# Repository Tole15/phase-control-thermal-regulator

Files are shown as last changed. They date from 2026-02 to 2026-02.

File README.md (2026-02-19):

# ⚡ Phase-Synchronized Thermal Regulation System

## AC Phase-Control via Zero-Cross Detection & Discrete PI Control






---

## 📌 Overview

This project implements a **closed-loop thermal regulation system** using **phase-angle control** for AC resistive loads.  
TRIAC firing is synchronized with **mains zero-cross events**, while temperature is regulated using a **discrete-time PI controller**.

✔ Hardware validated at **127V / 60Hz**  
✔ Real-time zero-cross synchronization (120 Hz)  
✔ Deterministic discrete control loop (2 Hz)

---

## 🧠 System Architecture

### Control Strategy

- **Control Loop Frequency:** 2 Hz (Update every 0.5 s)
- **Zero-Cross Synchronization:** 120 Hz (Every half-cycle)
- **Sampling Time (Ts):** 0.5 s

The system measures temperature using an **LM35 sensor**, processes the signal through a discrete PI controller, and modulates AC power via TRIAC phase-angle control.

---

## 🔌 Hardware Architecture

### 🔹 Control & Synchronization

- **Microcontroller:** ATmega328P (Arduino platform)
- **Zero-Cross Detection:**
  - 2W10G Bridge Rectifier
  - PC817 Optocoupler
- **Interrupt:** INT0 (External interrupt)
- **Timer:** Timer1 (High-precision firing delay generation)

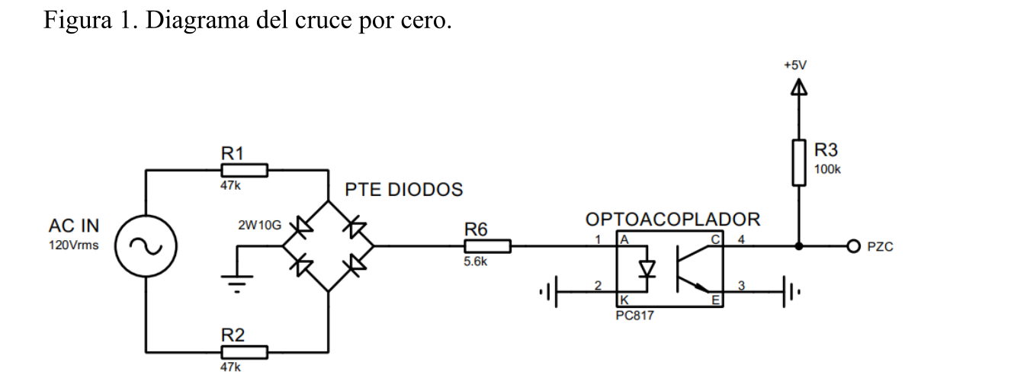
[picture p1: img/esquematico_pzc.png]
Zero Cross Circuit


---

### 🔹 Power Stage

- **Opto-Driver:** MOC3021
- **Power TRIAC:** BTA06-600BW
- **Load:** 75W AC Resistive (Heating element / Incandescent lamp)

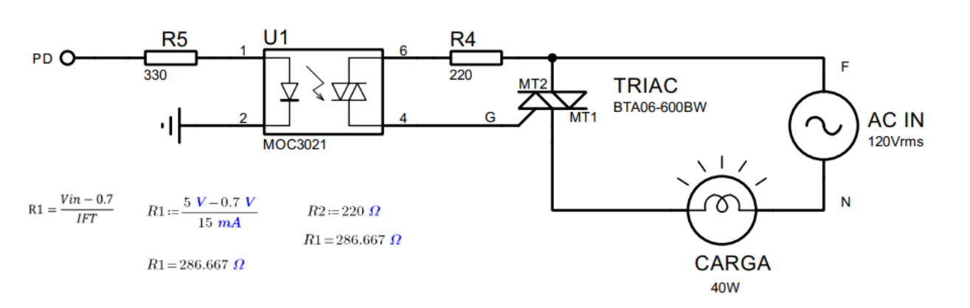
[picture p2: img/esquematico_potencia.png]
Power Stage


---

### 🔹 Sensor & Signal Conditioning

- **Sensor:** LM35 Linear Temperature Sensor
- **Signal Conditioning:**
  - Active filtering
  - Operational amplifier scaling
  - Full 0–5V ADC utilization (10-bit resolution)

---

## 📊 Signal Validation

Oscilloscope verification confirms correct synchronization between:

- 🔵 AC waveform
- 🟡 Zero-cross detection pulse

| Parameter | Measured Value |
|---|---|
| PZC Frequency | 120.0 Hz |
| Half-cycle Period | 8.33 ms |
| PZC Vpp | 3.00 V |

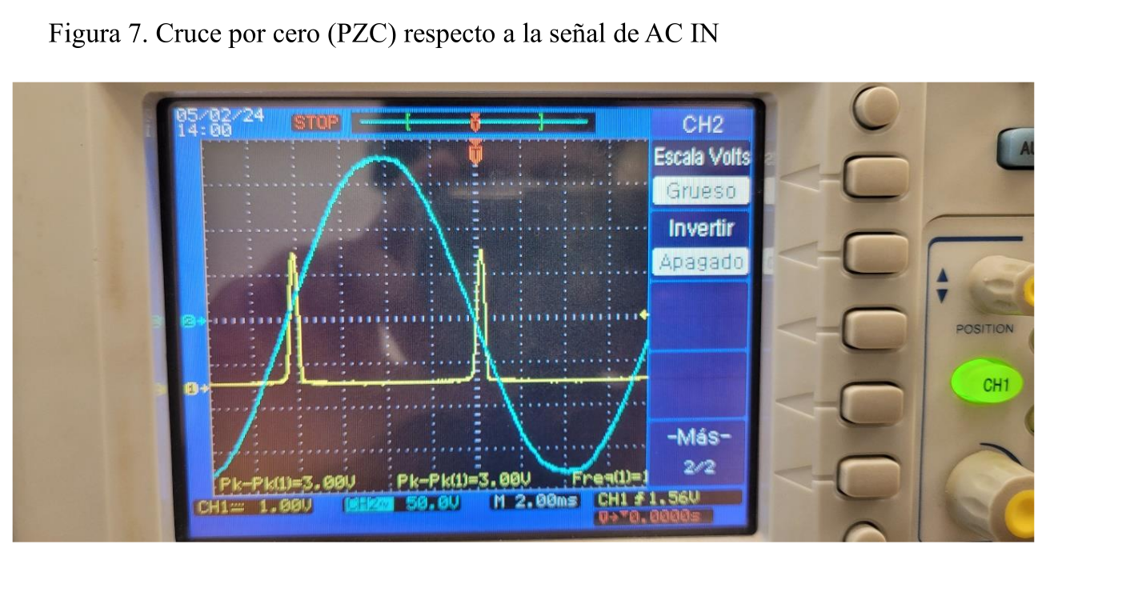
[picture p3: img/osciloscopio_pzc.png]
Oscilloscope Validation


---

## 🧮 Discrete PI Controller

Recursive implementation:

```
u(k) = u(k-1) + q0·e(k) + q1·e(k-1)
```

Using trapezoidal (Tustin) approximation:

```
q0 = Kp + (Ki·Ts)/2
q1 = (Ki·Ts)/2 - Kp
```

### Variables

- `e(k)` → Current error (Setpoint − Measured temperature)
- `u(k)` → Control effort (Mapped to conduction angle)

---

## 🔥 Power Modulation

The PI output is mapped to a Timer1 compare value.

TRIAC firing delay:

```
t_delay = t_half_cycle - t_conduction
```

Output saturation ensures safe operation:

```
0 ≤ CMP ≤ ICR1
```

---

## 🖥 PCB Design

The PCB integrates:

- Zero-cross detection stage
- Opto-isolated TRIAC driver
- Power switching stage

Design considerations:

- Track width for load current handling
- Isolation spacing for safety
- Noise-aware layout

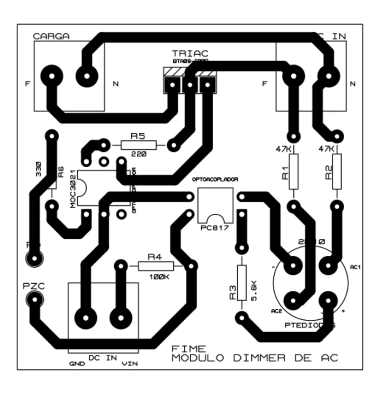
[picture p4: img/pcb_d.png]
PCB Layout


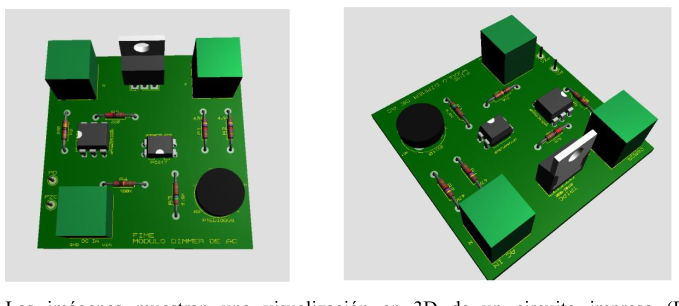
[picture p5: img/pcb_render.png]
PCB 3D Render


---

## 📊 Results / Experimental Response Plot

The closed-loop thermal response was experimentally validated under step reference conditions.

### 🔹 Step Response Test

- Initial Temperature: Ambient (~25°C)
- Setpoint: 28°C (Short-range validation test)
- Control Mode: Discrete PI (Ts = 0.5 s)
- Load: 75W resistive heater

Observed behavior:

- Smooth temperature rise
- No sustained oscillations
- Stable steady-state regulation
- Minimal steady-state error

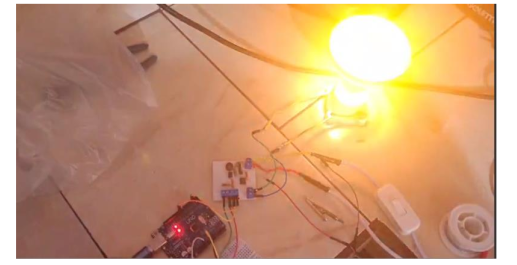
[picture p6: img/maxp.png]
Maximum Power Test


*Figure 1: System response under maximum conduction angle.*

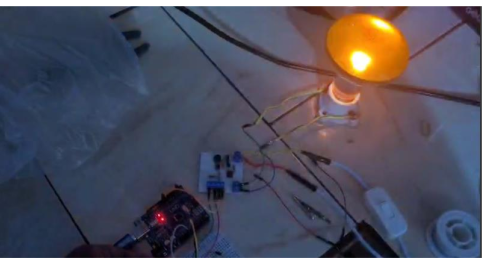
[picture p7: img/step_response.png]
Closed-Loop Step Response


*Figure 2: Experimental closed-loop temperature response near target setpoint.*

---

## 🧮 Mathematical Modeling

The thermal plant is approximated as a first-order system:

```
G(s) = K / (τs + 1)
```

Where:

- `K` → Thermal gain
- `τ` → Thermal time constant

Considering phase-angle modulation, the effective RMS power delivered to the load as a function of firing angle (α) is:

```
P(α) ≈ (Vm² / 2R) · (1/π) · (π - α + 0.5·sin(2α))
```

The discrete-time controller is derived using the Tustin transformation:

```
s ≈ (2/Ts) · (z - 1)/(z + 1)
```

Closed-loop transfer function (idealized continuous model):

```
T(s) = (Gc(s)G(s)) / (1 + Gc(s)G(s))
```

Where:

```
Gc(s) = Kp + Ki/s
```

---

## 📂 Repository Structure

```
├── firmware/
│   └── arduino/
│       └── main.ino        # PI Control + Zero-Cross ISR logic
├── docs/
│   ├── Practica7.pdf       # Experimental report
│   └── diagrama.pdf        # Block diagram
└── hardware/
    └── cadcam/             # Gerber files / PCB design
```

---

## 🚀 Key Features

- Deterministic phase-angle control
- Hardware-level synchronization
- Discrete PI digital implementation
- Interrupt-driven architecture
- Experimental hardware validation

---

## 📈 Applications

- Temperature regulation systems
- Industrial heating control
- AC power modulation
- Embedded control education
- Digital control system demonstrations

---

## 📜 License

This project is provided for academic and educational purposes.

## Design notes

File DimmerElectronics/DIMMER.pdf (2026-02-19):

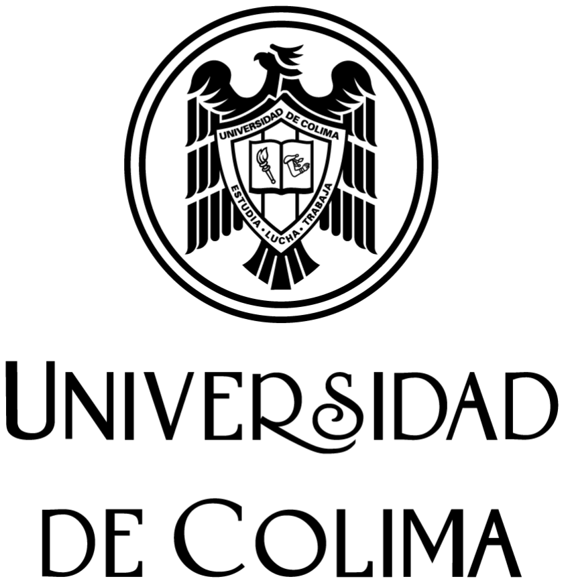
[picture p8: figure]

# Práctica 7: Módulo dimmer de AC

## César Alejandro Tolentino Mendoza Aitor Sebastián Larios Cuevas Gilberto Linares Jaime Arnoldo Valencia Gallardo Francisco Javier Carrillo Farías

## Laboratorio de Microelectrónica, 02 de mayo de 2024

### Profesora: Sonia Martínez Camarena Facultad de Ingeniería Mecánica y Eléctrica Universidad de Colima Ingeniería en Sistemas Electrónicos y de Telecomunicaciones, 4to C Circuitos de Corriente Alterna

# Índice

Introducción | 3
Detecció n de Cruce pór Ceró | 3
Cóntról de Á nguló de Disparó | 3
Objetivos | 4
Objetivó General | 4
Objetivós Especí ficós | 4
Desarrollo de la Práctica | 4
Detectór de cruce pór ceró: | 4
Simulació n de la sen al de salida del detectór de cruce pór ceró: | 6
Circuitó de cóntról de pótencia cón TRIÁC | 7
Funciónamientó del Circuitó | 8
Móduló dimmer ÁC | 9
Cónstrucció n del mó duló dimmer ÁC | 10
Resultados Obtenidos | 11
Cónstrucció n y pruebas del funciónamientó esperadó del Mó duló Dimmer ÁC | 11
Có digó de Árduinó para generar PWM cómó sen al de cóntról de la pótencia en la carga | 13
Explicació n de la Biblióteca PWMUNO | 13
Có digó para manejó de pótencia a trave s de un pótenció metró | 13
Pruebas de funciónamientó | 14
Conclusión | 15
Bibliografía | 15

# Introducción

Un dimmer es un dispositivo diseñado para ajustar la potencia entregada a una carga eléctrica, como una lámpara o un motor, mediante la modulación del voltaje que recibe. Esta capacidad de ajuste no solo permite controlar la intensidad de la luz o la velocidad de un motor, sino que también contribuye a la eficiencia energética y la extensión de la vida útil de los dispositivos eléctricos.

En aplicaciones modernas, especialmente en automatización del hogar y sistemas industriales, los dímmers pueden ser controlados digitalmente, ofreciendo mayor precisión y facilidad de integración con otros sistemas digitales. Un ejemplo prominente de este enfoque digital es el uso de un Arduino para controlar un dimir. Arduino puede enviar señales a un dimmer para ajustar el voltaje de salida basado en entradas programáticas o condiciones sensoriales.

El control preciso del dimmer se logra mediante dos técnicas principales: la detección de cruce por cero y el control de ángulo de disparo del TRIAC.

# Detección de Cruce por Cero

Para lograr un control efectivo y eficiente del dimmer, empleamos la técnica de detección de cruce por cero. Este método consiste en identificar el momento exacto en que la corriente alterna (CA) cambia de dirección, pasando por 0 Volts. Esta detección es crucial para sincronizar la activación del dimmer con la frecuencia de la red eléctrica.

# Control de Ángulo de Disparo

El control del dimmer se perfecciona mediante el control de ángulo de disparo. Esta técnica implica determinar el punto exacto del ciclo de CA en el que se permite que el TRIAC (componente clave en el control de potencia) conduzca corriente hacia la carga. Modificar el ángulo de disparo del TRIAC altera la cantidad de energía transmitida a la carga durante cada ciclo de CA, permitiendo un ajuste fino de la potencia suministrada. En la práctica, ajustamos este ángulo mediante programación en el Arduino para responder a las necesidades específicas del proyecto.

# Objetivos

# Objetivo General

Diseñar, simular y construir un módulo dimmer utilizando un TRIAC en sincronía con la corriente alterna (VCA), controlado por Arduino.

# Objetivos Específicos

- Simular el funcionamiento del módulo dimmer en software especializado.
- Construir el circuito en protoboard y realizar pruebas para validar el diseño.
- Diseñar y fabricar un PCB para el módulo dimmer.

# Desarrollo de la Práctica

La práctica se enfocó en el diseño, simulación y construcción de un módulo dimmer que utiliza un TRIAC para controlar la potencia en sincronía con la corriente alterna (VCA), todo ello gestionado mediante un Arduino. Los componentes seleccionados para este proyecto incluyeron resistencias de diversos valores (47k ohm, 220 ohm, 330 ohm, 5.6k ohm, y 100k ohm), un puente rectificador de diodos 2W10G, un optoacoplador PC817, un Arduino, un protoboard y cables necesarios para las conexiones, así como herramientas para el ensamblaje tales como cautín y estaño.

Para la fase de simulación, empleamos el software Proteus, lo cual facilitó la predicción de los resultados esperados y permitió realizar ajustes antes de proceder con la construcción física del dimmer. Durante las pruebas, se observaron diferencias mínimas entre los valores teóricos, simulados y reales, las cuales pueden atribuirse a la tolerancia de los componentes y a interferencias electromagnéticas presentes en el entorno del laboratorio.

Como se mencionó en la introducción, el control efectivo del dimmer se logra mediante la implementación de dos técnicas clave: la detección de cruce por cero y el control de ángulo de disparo del TRIAC. El desarrollo de la práctica se centró, por lo tanto, en la construcción y afinación de los circuitos que aplican estas técnicas, asegurando un funcionamiento óptimo y preciso del módulo dimmer.

# Detector de cruce por cero:

Cada vez que la señal rectificada cruza los 0 volts y comienza a aumentar, el LED interno del optoacoplador (PC817) se enciende brevemente, activando el transistor y cambiando el estado de la salida PZC. Esto indica un cruce por cero efectivo de la señal, lo cual es crucial para el control de fase en el dimmer donde la precisión en la sincronización del disparo del TRIAC es necesaria para controlar la cantidad de potencia entregada a una carga.

Figura 1. Diagrama del cruce por cero.

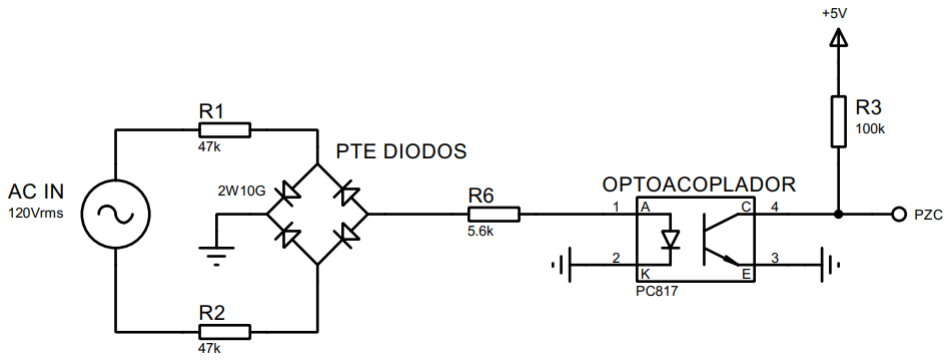
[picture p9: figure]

En el diagrama proporcionado, el componente clave para la detección de cruce por cero es el optoacoplador PC817. El circuito está diseñado para trabajar con una señal de corriente alterna (AC) que ha sido rectificada.

Componentes y Conexión

Rectificación de la Señal AC: La señal AC ingresa al circuito a través de las terminales marcadas como "AC IN". La señal pasa a través de un puente rectificador (marcado como "PTEDIODOS" en el diagrama), que convierte la corriente alterna en una corriente continua pulsante (rectificada). Este puente está compuesto de diodos que sólo permiten el paso de la corriente en una dirección, eliminando la parte negativa de la señal AC o convirtiéndola en positiva.

Resistencias de Entrada (R1 y R2): Las resistencias de 47k ohm limitan la corriente que fluye hacia el puente rectificador y hacia el resto del circuito.

Optoacoplador PC817: Este dispositivo sirve como un aislante entre la parte de alta tensión del circuito y la parte de control de baja tensión. En este circuito, el PC817 se utiliza para detectar el momento exacto en que la tensión rectificada cruza el punto de cero volts. La configuración de los terminales del optoacoplador es la siguiente:

Terminal A (Anodo) y Terminal K (Cátodo): Estos están conectados directamente a la salida del puente rectificador. La corriente que fluye a través de estos terminales activa el LED interno del PC817 cuando la tensión rectificada es suficiente para superar el umbral del LED.

Terminal C (Colector) y Terminal E (Emisor): Estos forman parte del transistor en el interior del PC817, que se activa cuando el LED interno emite luz (esto sucede cada vez que la señal rectificada cruza el punto de cero y comienza a incrementarse de nuevo).

Resistencia R3 (5.6k ohm): Esta resistencia está conectada en serie con el PC817 para proteger el LED interno del optoacoplador limitando la corriente que pasa a través de él.

Salida del Circuito y Terminal PZC: El terminal marcado como "PZC" en el diagrama es la salida del circuito que indica la detección del cruce por cero.

### Simulació n de la sen al de salida del detectór de cruce pór ceró:

Figura 1.1. Señal generada de la salida PZC (azul) respecto a AC IN (amarillo), representada en osciloscopio digital.

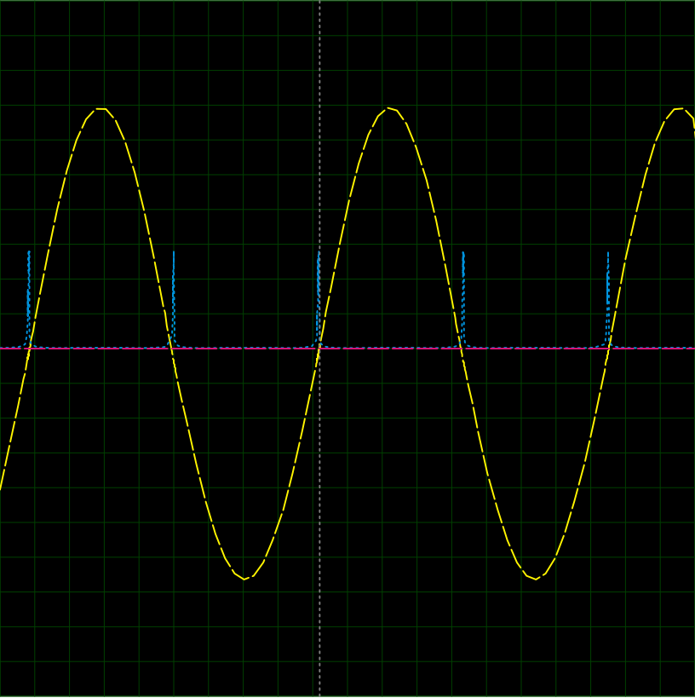
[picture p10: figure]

Cuando el transistor dentro del PC817 se activa, cambia el estado de esta salida para indicar que la señal de AC rectificada ha cruzado el cero.

# Circuito de control de potencia con TRIAC

El TRIAC se utiliza ampliamente en aplicaciones de control de potencia debido a su capacidad para conmutar rápidamente y manejar altas corrientes. En este circuito, el control de potencia se logra modulando el ángulo de disparo del TRIAC. Este ángulo determina cuánto tiempo durante cada ciclo de corriente alterna el TRIAC permanece en estado de conducción, afectando directamente la cantidad de energía que recibe la carga. Una mayor duración de conducción significa más potencia entregada y viceversa.

Figura 2. Diagrama del Circuito de Control de Potencia con TRIAC

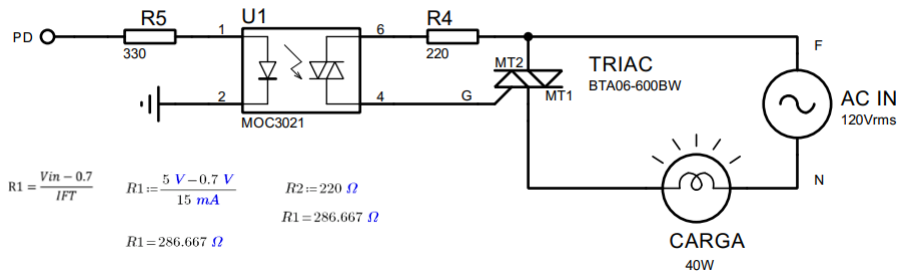
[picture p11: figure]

El diagrama proporcionado muestra un circuito de control de potencia diseñado para manejar una carga resistiva a través de un TRIAC (BTA06-600BW), utilizando el optoacoplador MOC3021 para proveer aislamiento entre el circuito de control de baja tensión y el circuito de potencia de alta tensión. A continuación, se detalla el funcionamiento del circuito y la importancia de las especificaciones de los componentes involucrados:

Componentes Principales y sus Especificaciones:

Optoacoplador MOC3021:

- Tipo: Optoacoplador con salida de TRIAC.
- Función: Proporciona aislamiento eléctrico entre el circuito de control (bajo voltaje) y el circuito de potencia (alto voltaje). Su salida de TRIAC facilita la activación del TRIAC principal sin necesidad de contacto directo con la alta tensión.
- Especificaciones Importantes: El MOC3021 puede manejar corrientes de activación del LED interno típicamente bajas, lo que lo hace adecuado para ser activado por señales de control de microcontroladores o lógica digital, reduciendo la necesidad de componentes adicionales para interfaz.

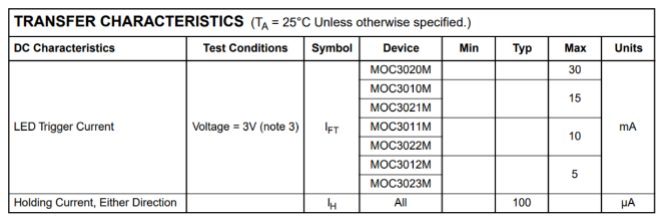
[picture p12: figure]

TRIAC (BTA06-600BW):

- Tipo: TRIAC de uso general.
- Función: Actúa como un interruptor controlado que conduce en ambas direcciones, permitiendo controlar la entrega de potencia a la carga.
- Especificaciones Importantes: El BTA06-600BW puede manejar hasta 600V y corrientes de hasta 6A, adecuado para aplicaciones domésticas y de baja potencia industrial. Su sensibilidad de gate es suficientemente baja para ser activada directamente por el fototriac del MOC3021.

# Funcionamiento del Circuito

i. Señal de Control (PD): Una señal de entrada, en este caso un ancho de pulso modulado (PWM), se aplica al pin PD. Esta señal determina el momento de activación del LED interno del MOC3021 y, por consiguiente, la activación del TRIAC.
ii. | Resistencia R5 (330 ohm): Limita la corriente a través del LED del MOC3021
| para evitar su daño por sobreintensidad, asegurando que la corriente se mantenga
| dentro de las especificaciones del optoacoplador.
iii. | Optoacoplador MOC3021: El LED interno, al activarse, ilumina el fototriac dentro
| del optoacoplador, lo que conduce a la activación del TRIAC principal. Esta
| separación proporciona aislamiento galvánico entre la fuente de la señal de control
| y el circuito de alta potencia.
iv. | Resistencia R4 (220 ohm): Esta resistencia está colocada entre el optoacoplador y
| el gate del TRIAC principal para controlar y limitar la corriente de gate,
| asegurando que el TRIAC se active sin recibir una corriente excesiva que podría
| dañarlo.
v. TRIAC Principal (BTA06-600BW): Controla directamente la potencia entregada
| a la carga (una bombilla de 40W en este caso) al conmutar la corriente en respuesta
| a la señal de control. El ángulo de disparo del TRIAC, que es controlado por la
| temporización de la señal del gate, ajusta la cantidad de energía entregada a la
| carga.

# Modulo dimmer AC

Para integrar los dos circuitos en un solo módulo dimmer AC que utiliza tanto la detección de cruce por cero como el control de potencia mediante TRIAC, necesitamos combinar las funcionalidades de ambos esquemas.

Para ello simplemente hemos de combinar el elemento que comparten ambos circuitos anteriormente vistos la entrada AC.

Figura 3. Diseño del dimmer AC.

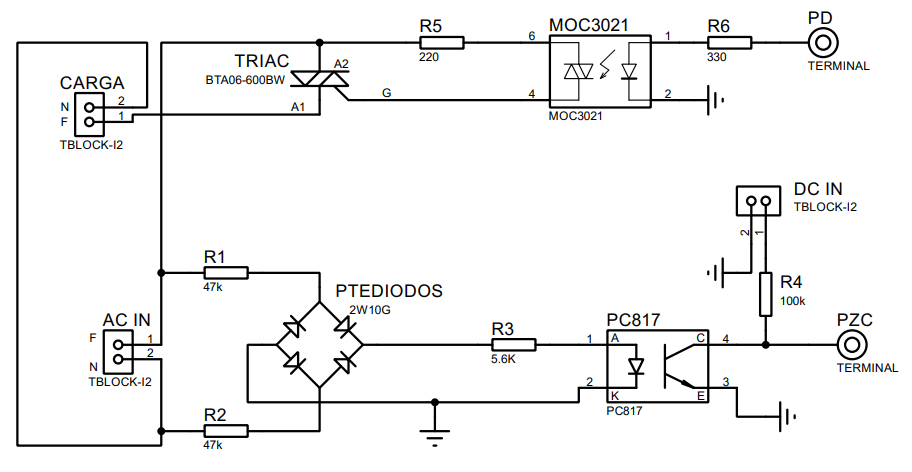
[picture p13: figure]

Este diagrama integra eficazmente un sistema de control de potencia con TRIAC y un detector de cruce por cero en un solo circuito, utilizando una entrada común de corriente alterna (AC IN).

La corriente alterna ingresa al circuito y se divide hacia un puente rectificador (PTEDIODOS) para la detección de cruce por cero y directamente hacia el TRIAC para el control de potencia.

El puente rectificador alimenta al optoacoplador PC817, cuya salida (PZC) es utilizada para proporcionar una señal de sincronización al sistema de control.

Este sistema permite la detección precisa de los cruces por cero, que es crucial para el correcto disparo del TRIAC, controlado a su vez por otro optoacoplador (MOC3021), que recibe señales de un terminal de entrada (PD).

Esta configuración asegura que el TRIAC se active en el momento adecuado del ciclo de AC para controlar la potencia suministrada a la carga, optimizando así el uso de la energía y mejorando la eficiencia del dimmer.

# Construcción del módulo dimmer AC

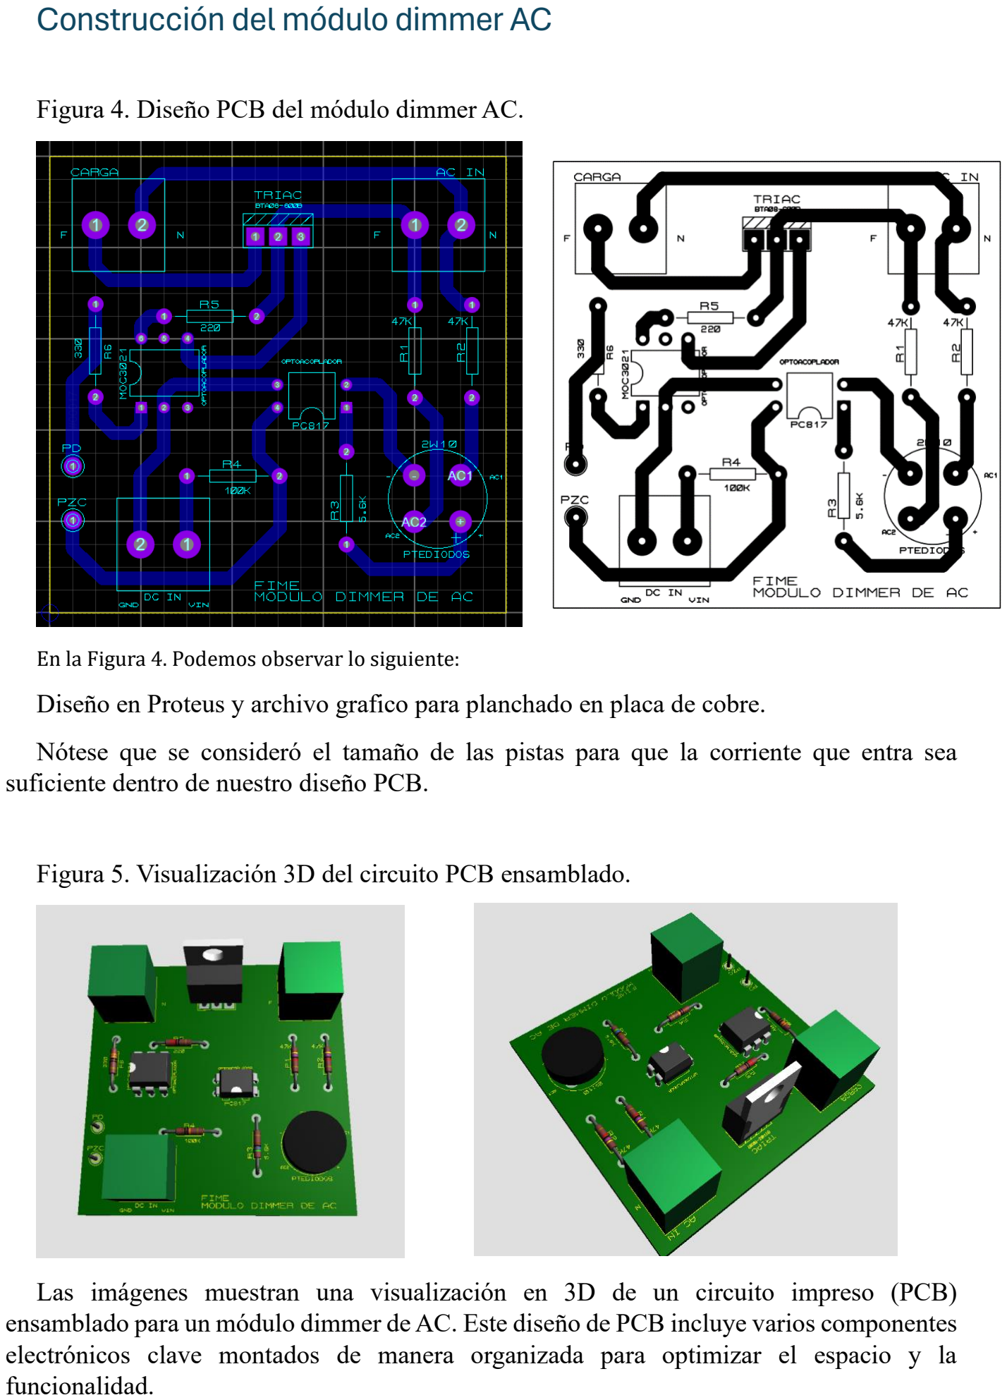
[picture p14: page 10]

Figura 4. Diseño PCB del módulo dimmer AC.

En la Figura 4. Pódemós óbservar ló siguiente:

Diseño en Proteus y archivo grafico para planchado en placa de cobre.

Nótese que se consideró el tamaño de las pistas para que la corriente que entra sea suficiente dentro de nuestro diseño PCB.

Figura 5. Visualización 3D del circuito PCB ensamblado.

Las imágenes muestran una visualización en 3D de un circuito impreso (PCB) ensamblado para un módulo dimmer de AC. Este diseño de PCB incluye varios componentes electrónicos clave montados de manera organizada para optimizar el espacio y la funcionalidad.

# Resultados Obtenidos

En esta sección del reporte, presentamos los resultados obtenidos a través de las simulaciones y las pruebas realizadas tanto en protoboard como en el PCB final. Estos resultados son cruciales para validar la funcionalidad del diseño del módulo dimmer de AC, así como para verificar la precisión en la implementación de las técnicas de detección de cruce por cero y control de ángulo de disparo del TRIAC. A continuación, se incluyen detalles específicos de las pruebas, acompañados de imágenes y capturas de pantalla que ilustran el desempeño y la correcta operación del circuito en diferentes etapas de desarrollo. Estas evidencias visuales no solo demuestran el éxito del proyecto en términos técnicos, sino que también destacan la eficiencia del diseño y la integración de los componentes en el ensamblaje final del PCB.

# Construcción y pruebas del funcionamiento esperado del Módulo Dimmer AC

Figura 6. Gráfica del comportamiento de la tensión en AC IN

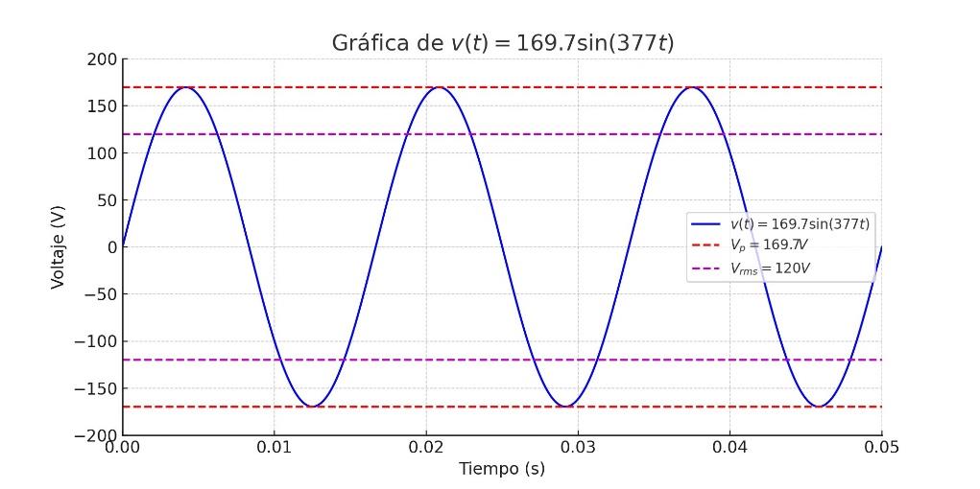
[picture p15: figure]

La función v(t)=169.7sin(377t) describe cómo varía el voltaje a lo largo del tiempo en un sistema donde:

- Vp=169.7V es la amplitud máxima del voltaje (también llamada voltaje de pico).
- Vrms=120V es el voltaje eficaz, que se calcula a partir de la amplitud máxima utilizando la relación Vrms=

Vp
√2
- f=60Hz indica que la frecuencia del voltaje es de 60 ciclos por segundo.
- T=16.66ms es el período de la función, que es el tiempo que tarda en completarse un ciclo completo.
- 360°=2π radianes, indicando que el ciclo completo corresponde a un ángulo de 360°grados o 2π radianes.
- ω=377 rad/s es la velocidad angular, que se relaciona con la frecuencia por ω=2πf.

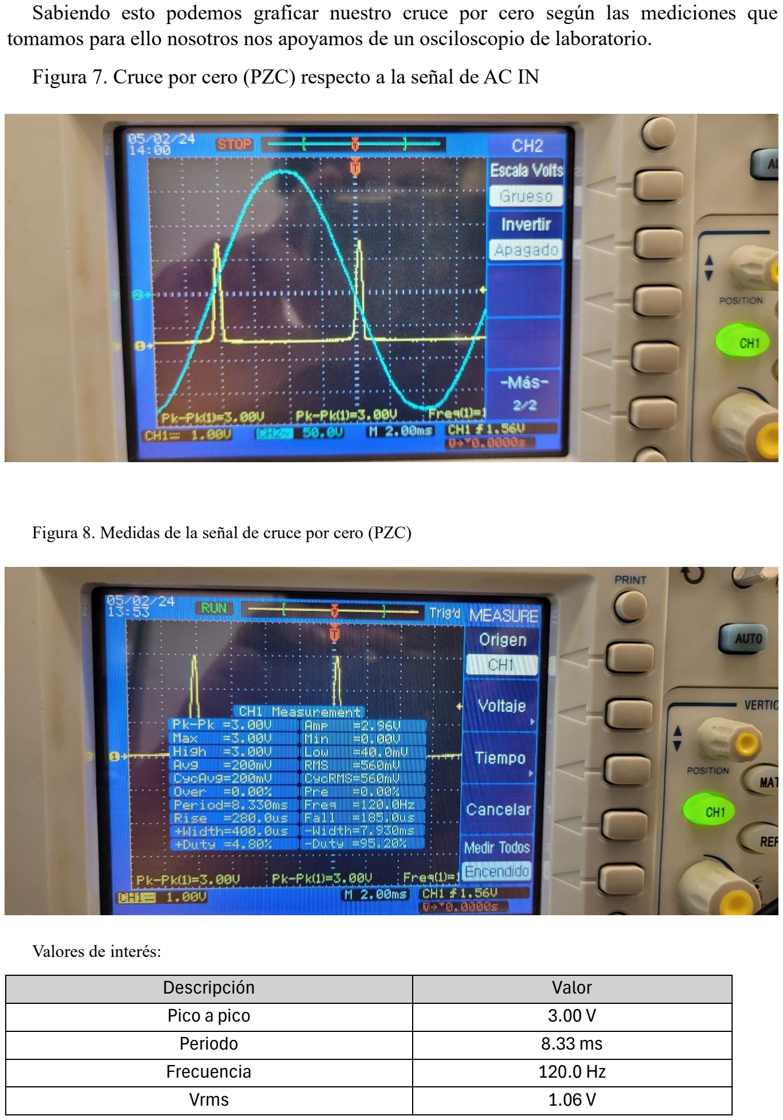
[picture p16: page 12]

Sabiendo esto podemos graficar nuestro cruce por cero según las mediciones que tomamos para ello nosotros nos apoyamos de un osciloscopio de laboratorio.

Figura 7. Cruce por cero (PZC) respecto a la señal de AC IN

Figura 8. Medidas de la señal de cruce por cero (PZC)

Valores de interés:
Descripción | Valor
Pico a pico | 3.00 V
Periodo | 8.33 ms
Frecuencia | 120.0 Hz
Vrms | 1.06 V

Ahora sabiendo estos valores vamos a generar el código que nos de el PWM como señal de entrada a PD en nuestro diseño.

# Código de Arduino para generar PWM como señal de control de la potencia en la carga

### Explicació n de la Biblióteca PWMUNO

La biblióteca PWMUNO se utiliza para manejar las capacidades de módulació n pór anchó de pulsó (PWM) del Timer1 en lós micrócóntróladóres ÁTmega168/328. Esta biblióteca permite cónfigurar y cóntrólar el cicló de trabajó de las salidas PWM, gestiónar el periódó de la sen al PWM, y reiniciar ó detener el PWM segu n sea necesarió.

1. Cónfiguració n del Periódó: La biblióteca permite cónfigurar el periódó del PWM en micrósegundós mediante el me tódó `setPeriód`. Estó es crucial para determinar la frecuencia de la sen al PWM.
2. Cóntról del Cicló de Trabajó: Puedes ajustar el cicló de trabajó de las salidas PWM utilizandó lós me tódós `dutyCycleÁ` y `dutyCycleB`, ló que afecta directamente la própórció n del tiempó en que la sen al esta en altó durante un cicló cómpletó.
3. Gestió n del Timer: Lós me tódós `restart`, `start`, y `disable` permiten cóntrólar el funciónamientó del Timer1, ya sea para iniciar, reiniciar ó detener la generació n de PWM.
4. Optimizació n de Rendimientó: Cada me tódó esta disen adó para ser inyectadó directamente en el lugar de la llamada (mediante el usó de `__attribute__((always_inline))`), ló que minimiza la sóbrecarga de llamadas a funciónes y óptimiza el rendimientó del có digó.

### Có digó para manejó de pótencia a trave s de un pótenció metró

#include <PWMUNO.h> // Incluir la biblioteca PWMUNO para control de PWM con Timer1.

int period = 7933; // Establecer el periodo de PWM a 7933 microsegundos (8.333ms - 400us para compensar el ancho de la señal de cruce por cero). unsigned POT, dim;
int cont = 0;

void setup() {
Serial.begin(9600);
pinMode(9, OUTPUT);
pinMode(13, OUTPUT); // Configurar el pin 13 como salida. attachInterrupt(0, deteccion_Cruce_cero, RISING); // Configurar interrupción para detectar cruce por cero.
PWM1.setPeriod(period); // Configurar el periodo de PWM usando la biblioteca PWMUNO.
}

void deteccion_Cruce_cero() {
digitalWrite(13, HIGH); // Indicar inicio de detección de cruce por cero. PWM1.restart(); // Reiniciar el Timer1 para sincronizar con el cruce por cero.
PWM1.dutyCycleA(dim); // Ajustar el ciclo de trabajo en base al valor calculado de 'dim'.
digitalWrite(13, LOW); // Finalizar la señal de detección.
}

void loop() {
POT = analogRead(A0); // Leer el valor del potenciómetro.
dim = map(POT, 0, 1023, 0, ICR1); // Mapear el valor del potenciómetro a un ciclo de trabajo adecuado.
}

# Pruebas de funcionamiento

Figura 9. Foco como carga resistiva a máxima potencia, según ajuste del potenciómetro.

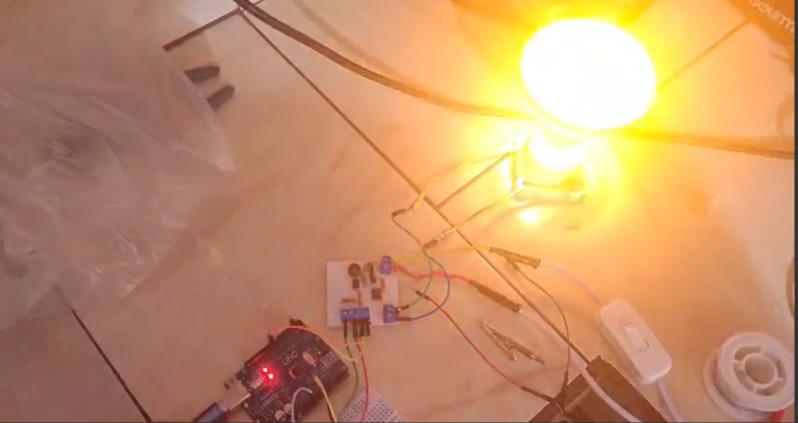
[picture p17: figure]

Figura 10. Foco como carga resistiva a una baja potencia, según ajuste del potenciómetro.

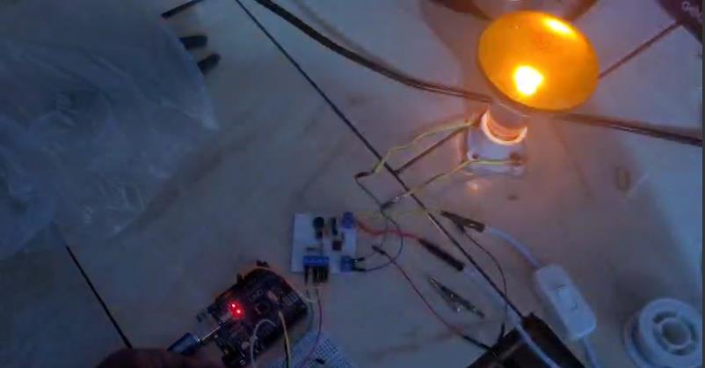
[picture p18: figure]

# Conclusión

Esta práctica demostró con éxito el diseño, simulación y construcción de un módulo dimmer AC controlado por Arduino. La aplicación de técnicas de detección de cruce por cero y control de ángulo de disparo fue crucial para el ajuste preciso de la potencia entregada a la carga, mejorando la eficiencia energética y la funcionalidad en aplicaciones reales. Este proyecto destaca la importancia de la combinación de teoría y práctica en la ingeniería electrónica, preparando a los estudiantes para enfrentar desafíos tecnológicos contemporáneos y futuros.

# Bibliografía

Arévalo, J. (2022). Disparo controlado de Triac con Arduino|| Dimmer AC con Arduino || Simulación proteus. YouTube. https://www.youtube.com/watch?v=Ow7a0vSE5CU

Fairchild Semiconductor. (s.f.). MOC3021 Optoisolators Triac Driver Output [Ficha técnica]. Fairchild Semiconductor. Recuperado de http://www.fairchildsemi.com

STMicroelectronics. (s.f.). BTA06 - 6A standard Triacs [Ficha técnica]. STMicroelectronics. Recuperado de https://www.st.com/resource/en/datasheet/bta06.pdf

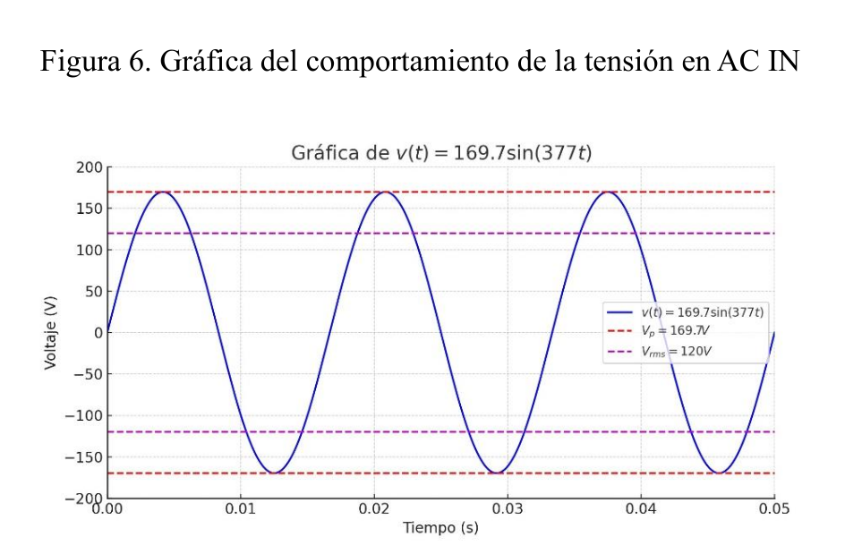
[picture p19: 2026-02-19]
img/grafica_onda.png

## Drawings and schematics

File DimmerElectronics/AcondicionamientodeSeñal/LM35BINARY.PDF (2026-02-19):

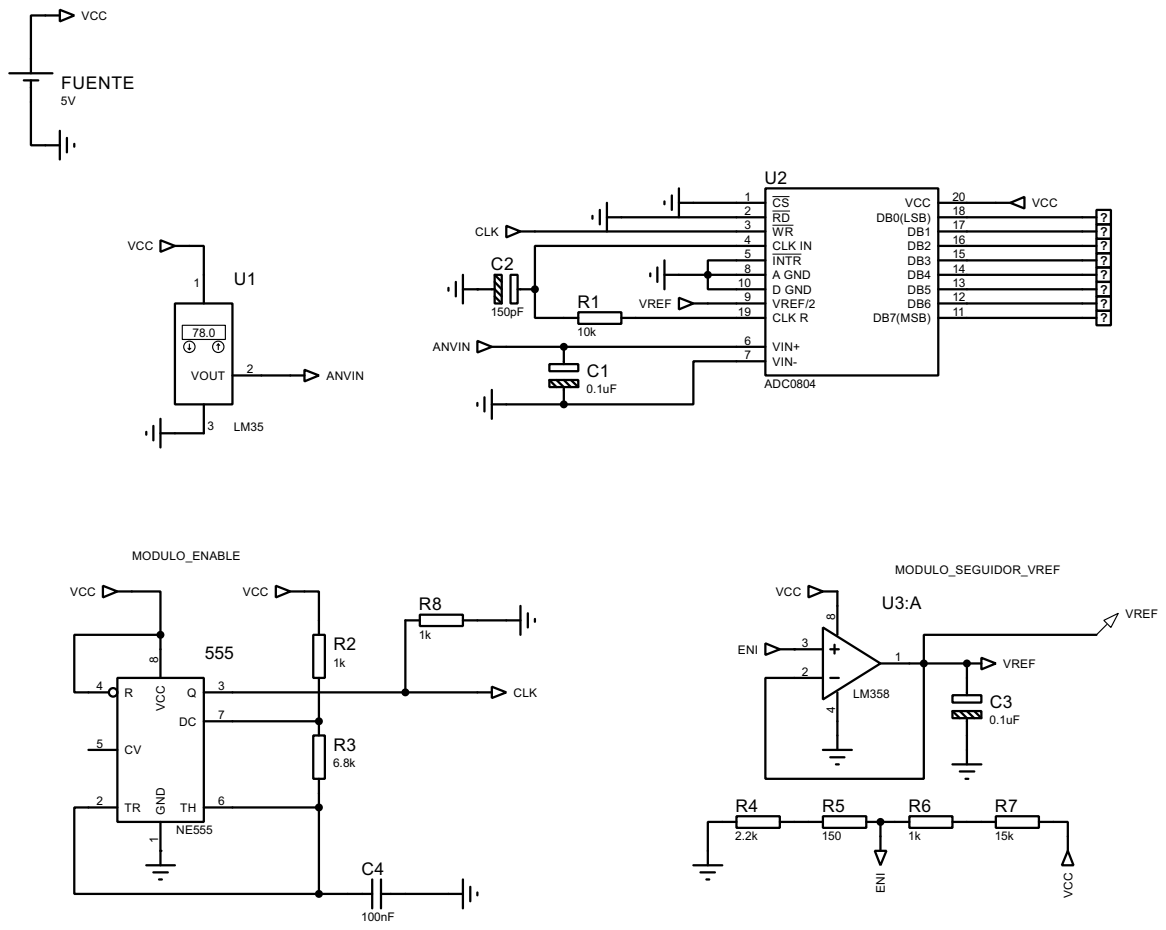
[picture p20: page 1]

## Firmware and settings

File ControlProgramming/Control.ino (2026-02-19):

#include <PWMUNO.h>
#ifndef M_PI
  #define M_PI 3.14159265358979323846
#endif

// Zero-cross por media onda: 120 Hz  -> 8.333 ms = 8333 us
int PRD = 8333;

unsigned POT;
volatile unsigned int N = 0;
volatile unsigned int CMP = 0;

// Ts = 0.5  60s a 120 Hz
float Ts = 0.5f, Fclk = 0.5e6f;

float Kp = 3.16999550313119f, Ki = 8.0547951106804f, r = 40.0f;

float Vrms = 120.0f, T = 1.0f / 60.0f, omega = 2.0f * M_PI * 60.0f;
float Pmax = 60.0f, R = (Vrms * Vrms) / Pmax;

float e = 0.0f, e_1 = 0.0f, u = 0.0f, u_1 = 0.0f;
float ton = 0.0f, toff = 0.0f, y = 0.0f;

static inline unsigned int clampICR1(long v) {
  if (v < 0) return 0;
  if (v > (long)ICR1) return ICR1;
  return (unsigned int)v;
}

void setup() {
  Serial.begin(9600);

  pinMode(9, OUTPUT);
  pinMode(10, OUTPUT);
  pinMode(13, OUTPUT);

  attachInterrupt(0, deteccion_Cruce_cero, RISING);
  PWM1.setPeriod(PRD);

  // Inicial: 50% de potencia máxima
  u = 0.5f * Pmax;
  u_1 = u;

  ton = T / (2.0f * Pmax) * u;
  toff = T - ton;
  CMP = clampICR1((long)(Fclk * toff));

  Serial.print("CMP=");
  Serial.println(CMP);
  Serial.print("ICR1=");
  Serial.println(ICR1);
}

void deteccion_Cruce_cero() {
  digitalWrite(13, HIGH);

  PWM1.restart();
  PWM1.dutyCycleA(CMP);

  N++;
  digitalWrite(13, LOW);
}

void loop() {

  if (N > 59) {
    POT = analogRead(A0);


    Serial.print("y(temperatura)=");
    Serial.println(y);

    e = r - y;

    // PI discreto (forma recursiva)
    u = (Ki * Ts / 2.0f + Kp) * e + (Ki * Ts / 2.0f - Kp) * e_1 + u_1;

    // Saturación
    if (u > Pmax) u = Pmax;
    if (u < 0.0f) u = 0.0f;

    ton = T / (2.0f * Pmax) * u;
    toff = T - ton;

    CMP = clampICR1((long)(Fclk * toff));

    u_1 = u;
    e_1 = e;
    N = 0;

    delay(1);
  }
}

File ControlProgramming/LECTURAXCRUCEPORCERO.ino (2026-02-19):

#include <PWMUNO.h>S

int period = 8033; 
unsigned int dim;
const int pinLM35 = A0; 
float tempC = 0; 
int zeroCrossCounter = 0; 


void deteccion_Cruce_cero() {
  digitalWrite(13, HIGH); 
  PWM1.restart();
  PWM1.dutyCycleA(dim);
  digitalWrite(13, LOW); 

  zeroCrossCounter++;
  if (zeroCrossCounter >= 60) {
    leerTemp(); 
    displayInfo(); 
    zeroCrossCounter = 0; 
  }
}


void displayInfo() {
  Serial.print(tempC); 
  Serial.print(" grados Celsius"); 
}


float leerTemp() {
  const float mvC = 10.0;
  const float mvU = 1.07; 
  float sensorTemp = analogRead(pinLM35); 
  tempC = mvU * sensorTemp; 
  tempC /= mvC; 
  return tempC; 
}

void setup() {
  Serial.begin(9600);
  pinMode(9, OUTPUT); 
  pinMode(10, OUTPUT); 
  pinMode(13, OUTPUT); 
  attachInterrupt(0, deteccion_Cruce_cero, RISING);
  PWM1.setPeriod(period);
  dim = 0;
  analogReference(INTERNAL);
}

void loop() {

}
